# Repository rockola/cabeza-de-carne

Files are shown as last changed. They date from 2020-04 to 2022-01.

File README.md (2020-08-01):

# cabeza-de-carne
Yet another Meathead clone

* v0.1: initial import, complete, unverified
* v0.2: more compact board, 3mm LED
* v0.3: longer footprint for D2 (not standing anymore), fixed silkscreen for Q2 (had wrong markings for B,C), verified

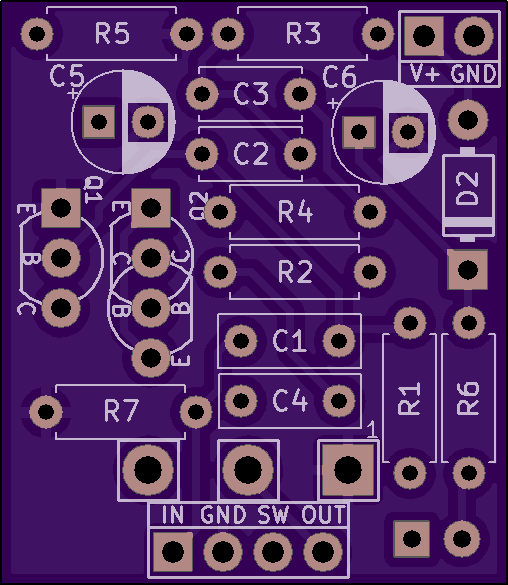
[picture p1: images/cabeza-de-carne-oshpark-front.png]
Front

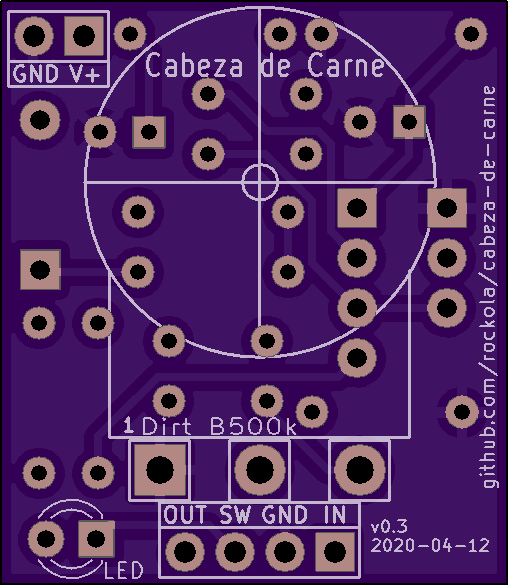
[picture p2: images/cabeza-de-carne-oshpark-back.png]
Back


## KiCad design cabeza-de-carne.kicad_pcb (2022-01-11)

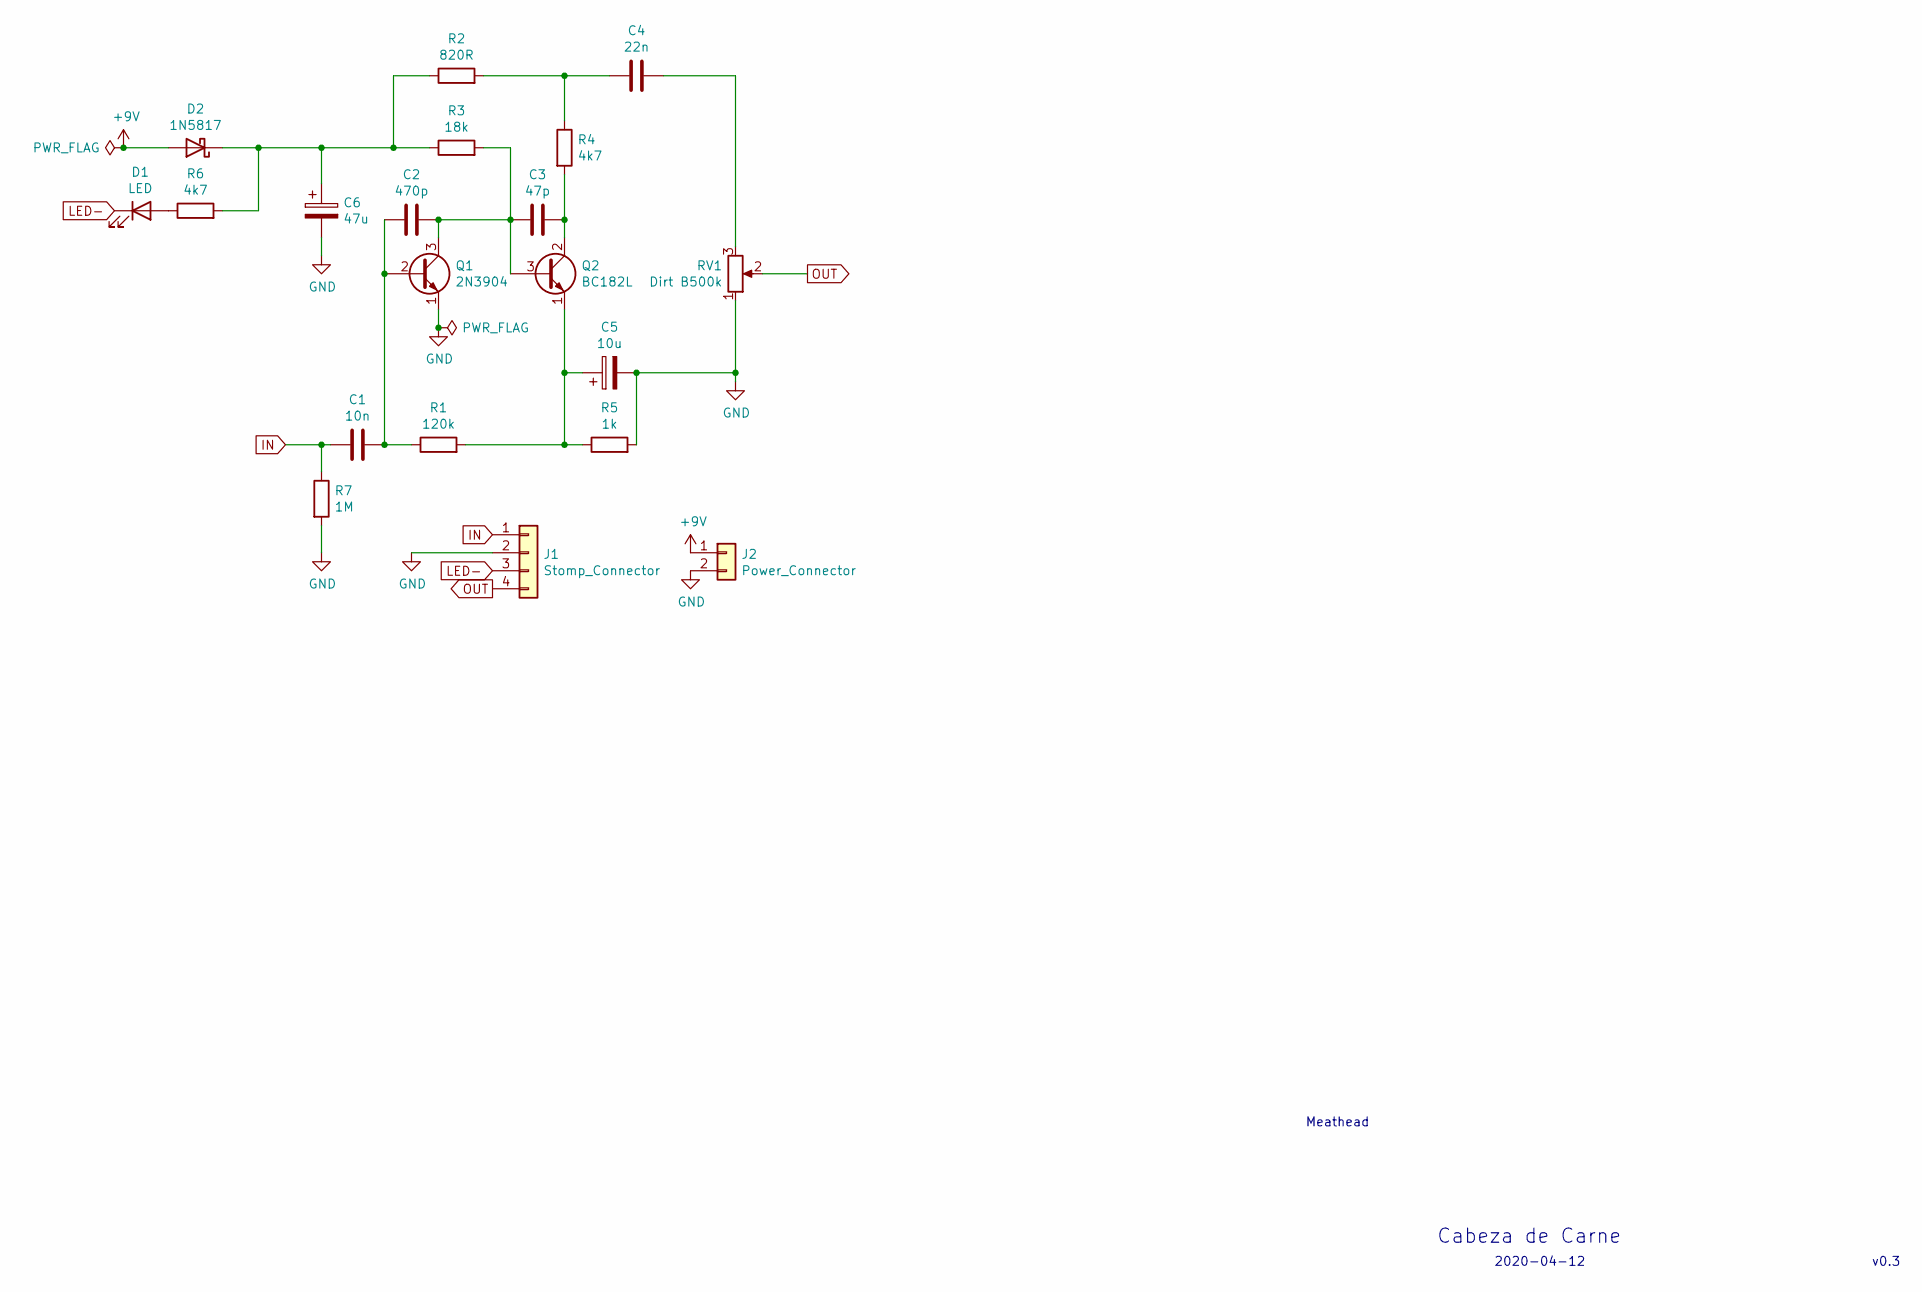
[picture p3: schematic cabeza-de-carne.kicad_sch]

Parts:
C1: 10n; C_Rect_L7.0mm_W2.5mm_P5.00mm
C2: 470p; C_Disc_D5.0mm_W2.5mm_P5.00mm
C3: 47p; C_Disc_D5.0mm_W2.5mm_P5.00mm
C4: 22n; C_Rect_L7.0mm_W2.5mm_P5.00mm
C5: 10u; CP_Radial_D5.0mm_P2.50mm
C6: 47u; CP_Radial_D5.0mm_P2.50mm
D1: LED; LED_D3.0mm
D2: 1N5817; DO41-3
J1: Stomp_Connector; Stomp_4pin
J2: Power_Connector; Power_Header_2pin_TOP
Q1: 2N3904; TO92_EBC
Q2: BC182L; TO92_ECBE
R1: 120k; R_Axial_DIN0207_L6.3mm_D2.5mm_P7.62mm_Horizontal
R2: 820R; R_Axial_DIN0207_L6.3mm_D2.5mm_P7.62mm_Horizontal
R3: 18k; R_Axial_DIN0207_L6.3mm_D2.5mm_P7.62mm_Horizontal
R4, R6: 4k7; R_Axial_DIN0207_L6.3mm_D2.5mm_P7.62mm_Horizontal
R5: 1k; R_Axial_DIN0207_L6.3mm_D2.5mm_P7.62mm_Horizontal
R7: 1M; R_Axial_DIN0207_L6.3mm_D2.5mm_P7.62mm_Horizontal
RV1: Dirt B500k; 16mm_BoardMount

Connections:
+9V: D2.2 (A), J2.1 (PWR)
GND: C5.2, C6.2, J1.2 (GND), J2.2 (GND), Q1.1 (E), R5.2, R7.2, RV1.1
IN: C1.1, J1.1 (IN), R7.1
LED-: D1.1 (K), J1.3 (SW)
unnamed: C1.2, C2.1, Q1.2 (B), R1.1
unnamed: C2.2, C3.1, Q1.3 (C), Q2.3 (B), R3.2
unnamed: C3.2, Q2.2 (C), R4.2
unnamed: C4.1, R2.2, R4.1
unnamed: C4.2, RV1.3
unnamed: C5.1, Q2.1 (E), R1.2, R5.1
unnamed: C6.1, D2.1 (K), R2.1, R3.1, R6.2
unnamed: D1.2 (A), R6.1
OUT: J1.4 (OUT), RV1.2

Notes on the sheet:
v0.3
2020-04-12
Cabeza de Carne
Meathead

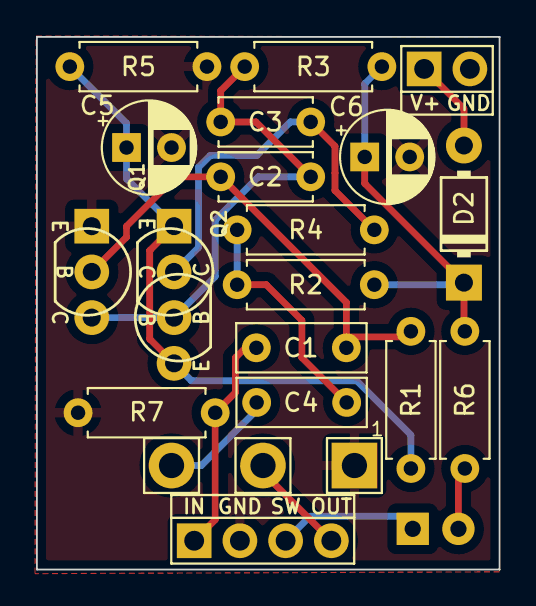
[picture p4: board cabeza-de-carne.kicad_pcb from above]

Board: 2 copper layers, 25.7 x 29.6 mm, 20 parts (1 on the bottom side), 13 nets.

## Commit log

2020-03-12 initial Gerbers
    [cabeza-de-carne-B_Cu.gbl, cabeza-de-carne-B_Mask.gbs, cabeza-de-carne-B_Paste.gbp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]
2020-03-13 0.2: more compact board
    [cabeza-de-carne-B_Cu.gbl, cabeza-de-carne-B_Mask.gbs, cabeza-de-carne-B_Paste.gbp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]
2020-04-12 v0.3: longer footprint for D1 (not standing anymore), fixed silkscreen for Q2 (had wrong markings for B,C)
    [cabeza-de-carne.kicad_pcb, cabeza-de-carne.sch]
2020-04-12 v0.3 gerbers, images
    [cabeza-de-carne-B_Cu.gbl, cabeza-de-carne-B_Mask.gbs, cabeza-de-carne-B_Paste.gbp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]
2022-01-11 updated to KiCad 6.0
    [cabeza-de-carne-B_Cu.gbl, cabeza-de-carne-B_Mask.gbs, cabeza-de-carne-B_Paste.gbp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]
